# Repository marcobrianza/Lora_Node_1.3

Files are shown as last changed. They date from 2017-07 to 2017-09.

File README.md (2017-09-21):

# LoRa Node 1.3
PCB design by Mauro Alfieri and Marco Brianza

A LoRa shield for [WeMos](https://www.wemos.cc/) D1 mini boards  
Made to experiment a LoRaWan radio node and single channel gateway.
based on the projects:  

* WeMos-Lora [https://github.com/hallard/WeMos-Lora](https://github.com/hallard/WeMos-Lora)
* Wemos shield template [https://github.com/SuperHouse/D1MSHO](https://github.com/SuperHouse/D1MSHO)

PCB tested ready for manufactoring:  

* PCBWay [https://www.pcbway.com/project/shareproject/LoRa_Node_1_3.html](https://www.pcbway.com/project/shareproject/LoRa_Node_1_3.html)  
* PCBs.io [https://PCBs.io/share/4XRGg](https://PCBs.io/share/4XRGg) 

The reference BOM:  
[http://www.tme.eu/parking/d9c2f42be567335629e84ae2b3406e02d69110b7.html
](http://www.tme.eu/parking/d9c2f42be567335629e84ae2b3406e02d69110b7.html)

To use the board as node use this version of the lmic LoRa library:  
[https://github.com/marcobrianza/arduino-lmic](https://github.com/marcobrianza/arduino-lmic)  
It supports the LoraNode 1.3 pinout and fixes the radio power setting

Some practial examples with wrapping of the LMIC in more Arduinistic way are here:
[https://github.com/marcobrianza/LoraNode_Examples](https://github.com/marcobrianza/LoraNode_Examples)

To use it as gateway this repo:  
[https://github.com/marcobrianza/ESP-1ch-Gateway-v4.0/tree/LoraNode_1.3](https://github.com/marcobrianza/ESP-1ch-Gateway-v4.0/tree/LoraNode_1.3) 

## Usage Notes
The pinout is as the following table  
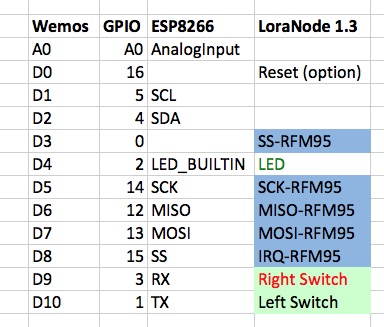
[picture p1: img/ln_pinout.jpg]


* I2C pins are free to be used for sensors or GPIO (pull up resistor are optional on the bottom) 
* D0 is free and can be connected to Reset with the "sleep" pad on the bottom of the board 
* The 2 switches (normally opened) are shared with the serial port pins
* The LED is connecred in parallel with the Built in LED of Wemos 

## Pictures

The board assembled top and bottom
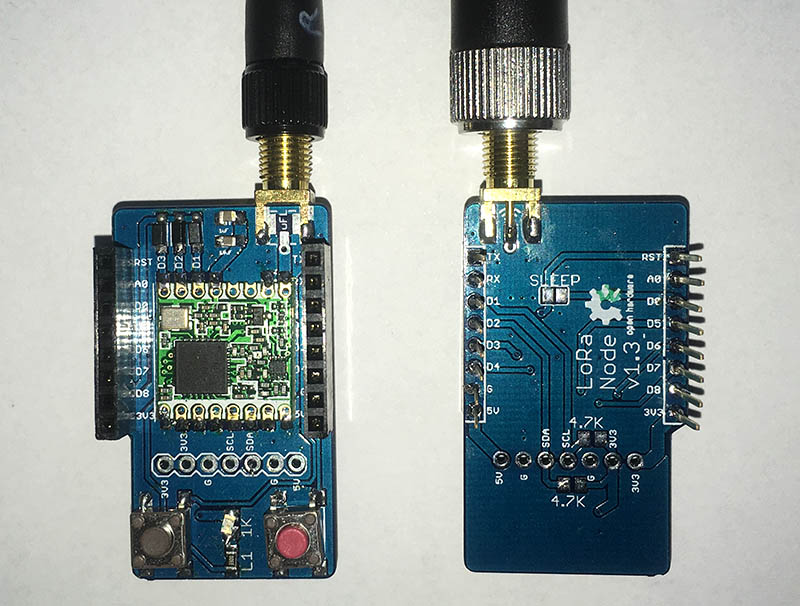
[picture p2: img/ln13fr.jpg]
LoraNode_1.3 top and bottom


The board in use as node and gateway with wemos oled display
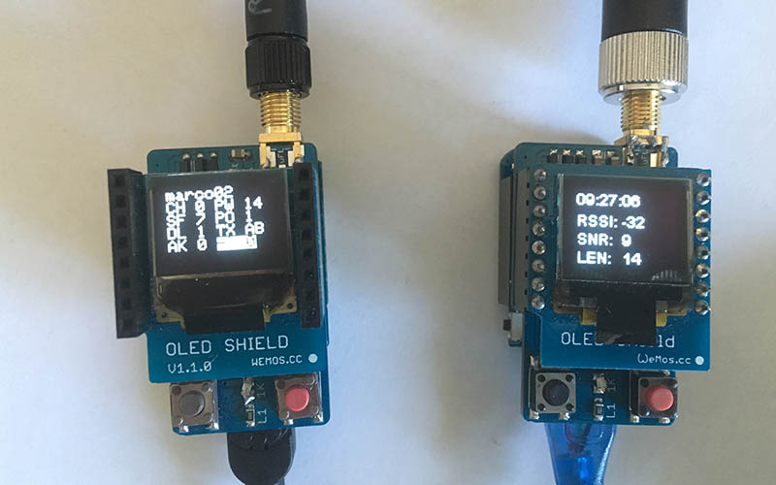
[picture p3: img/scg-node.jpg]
LoraNode_1.3 node and gateway


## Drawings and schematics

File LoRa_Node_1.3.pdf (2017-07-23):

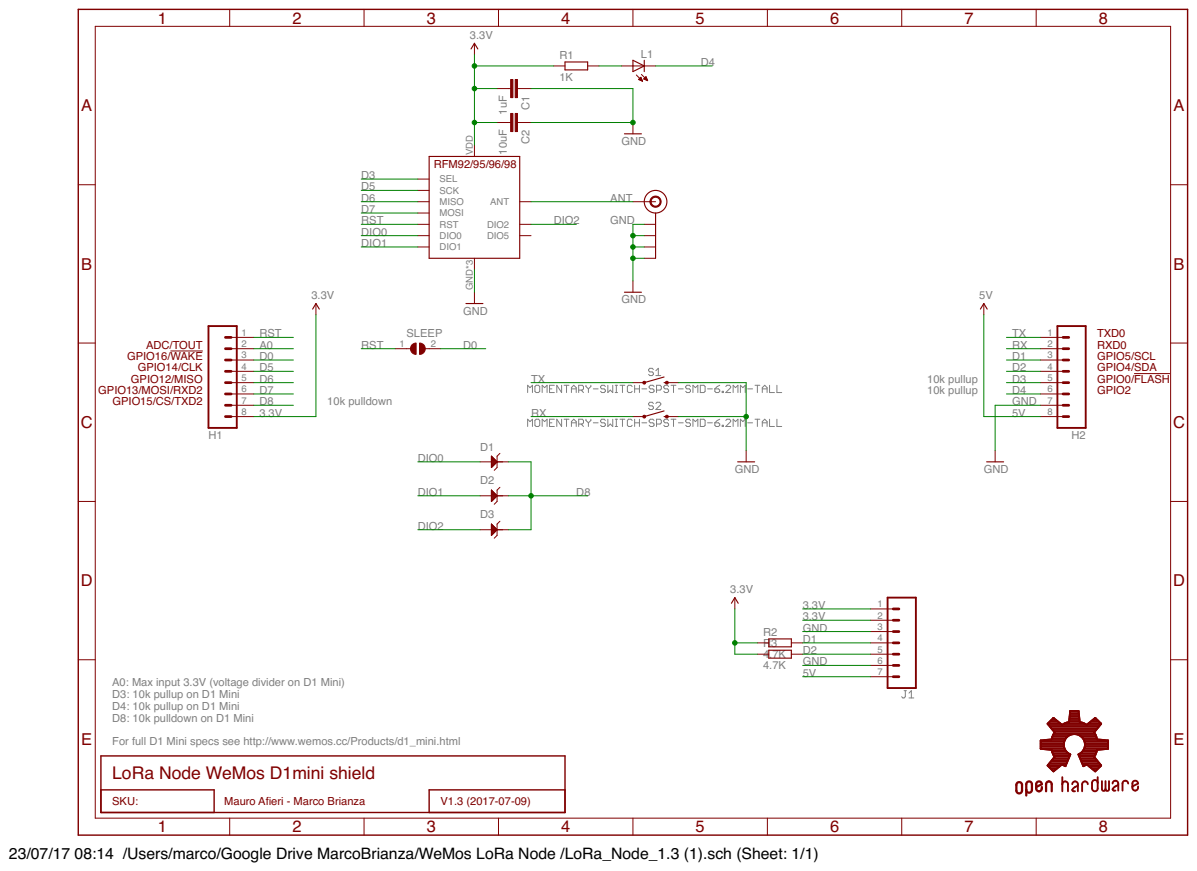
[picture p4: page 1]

A0: Max input 3.3V (voltage divider on D1 Mini)
D3: 10k pullup on D1 Mini
D4: 10k pullup on D1 Mini
D8: 10k pulldown on D1 Mini
For full D1 Mini specs see http://www.wemos.cc/Products/d1_mini.html
SKU: LoRa Node WeMos D1mini shield

23/07/17 08:14 /Users/marco/Google Drive MarcoBrianza/WeMos LoRa Node /LoRa_Node_1.3 (1).sch (Sheet: 1/1)

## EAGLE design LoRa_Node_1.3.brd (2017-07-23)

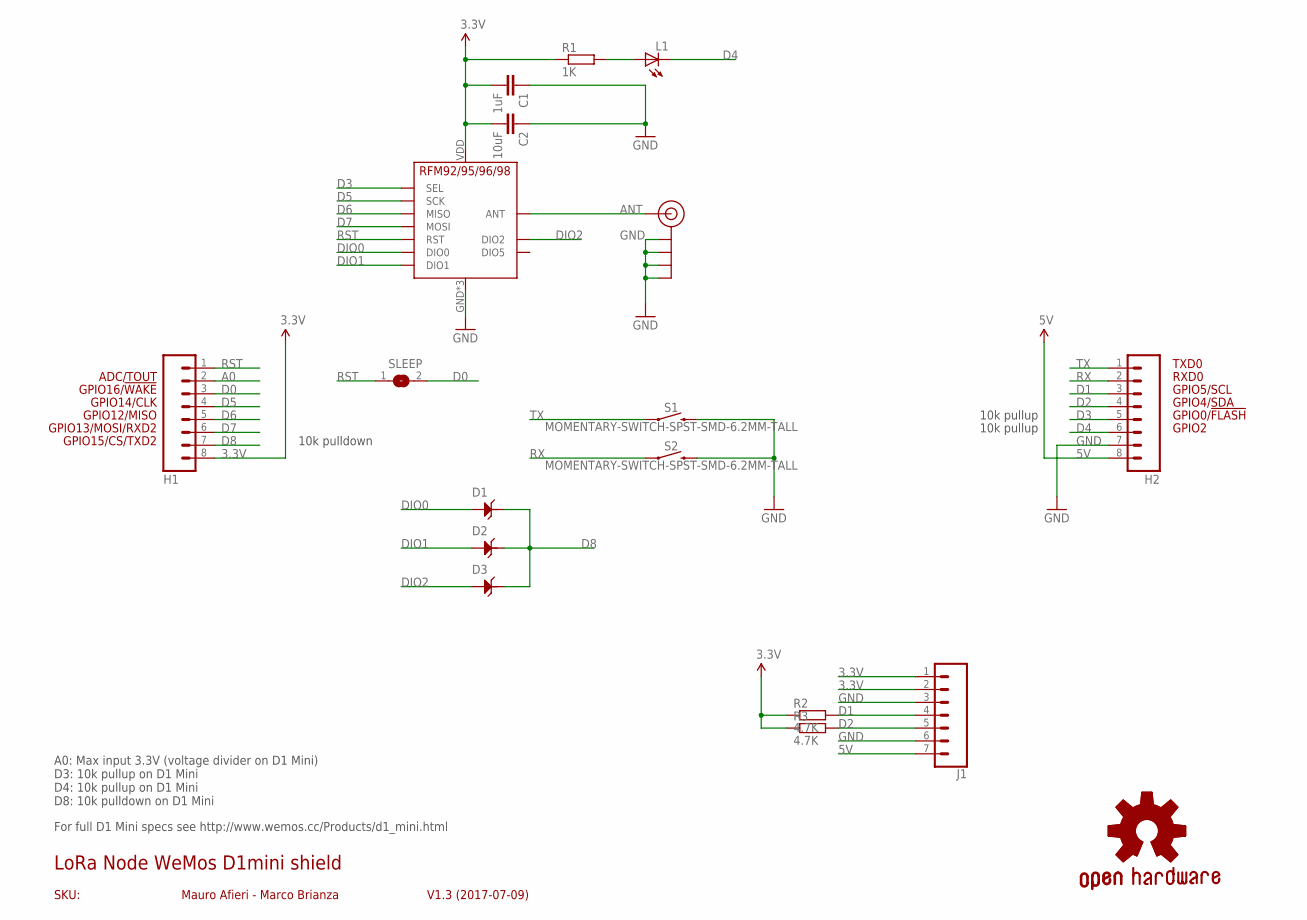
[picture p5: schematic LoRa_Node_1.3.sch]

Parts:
C1: 1uF; 0805-CAP-LARGEPADS
C2: 10uF; 0805-CAP-LARGEPADS
D1, D2, D3: D-ESD-2P-CESD5V0D1; SOD123-2.7X1.6
GOLD_ORB_SM1: OSHWLOGO_GOLD_ORB_SM; OSHW2
H1, H2: M08; 1X08
J1: CONN_07; 1X07
J$1: ANTENNATINY; SMA_UFL_PAD_TINY
L1: LEDCHIPLED_0805; CHIPLED_0805
R1: 1K; M0805
R2, R3: 4.7K; M0805
S1, S2: MOMENTARY-SWITCH-SPST-SMD-6.2MM-TALL; TACTILE_SWITCH_SMD_6.2MM_TALL
SLEEP: SJ
U$2: RFM95

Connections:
3.3V: C1.2, C2.2, H1.8, J1.1, J1.2, R1.1, R2.1, R3.1, U$2.VDD (VCC)
5V: H2.8, J1.7
A0: H1.2
ANT: J$1.ANT1 (SIGNAL), J$1.ANT2 (SIGNAL), J$1.ANT3 (SIGNAL), U$2.ANT
D0: H1.3, SLEEP.2
D1: H2.3, J1.4, R2.2
D2: H2.4, J1.5, R3.2
D3: H2.5, U$2.NSS (SEL)
D4: H2.6, L1.C
D5: H1.4, U$2.SCK
D6: H1.5, U$2.MISO
D7: H1.6, U$2.MOSI
D8: D1.2, D2.2, D3.2, H1.7
DIO0: D1.1, U$2.DIO0
DIO1: D2.1, U$2.DIO1
DIO2: D3.1, U$2.DIO2
GND: C1.1, C2.1, H2.7, J1.3, J1.6, J$1.GND1 (GND), J$1.GND2 (GND), J$1.GND3 (GND), J$1.GND4 (GND), S1.B2 (2), S2.B2 (2), U$2.GND, U$2.GND1 (GND), U$2.GND2 (GND)
unnamed: L1.A, R1.2
RST: H1.1, SLEEP.1, U$2.RST
RX: H2.2, S2.A2 (1)
TX: H2.1, S1.A2 (1)

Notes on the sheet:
GPIO2
GPIO0/!FLASH
GPIO12/MISO
GPIO4/SDA
GPIO5/SCL
RXD0
TXD0
GPIO13/MOSI/RXD2
GPIO14/CLK
GPIO15/CS/TXD2
GPIO16/!WAKE
SKU:
LoRa Node WeMos D1mini shield
V1.3 (2017-07-09)
Mauro Afieri - Marco Brianza
ADC/TOUT
A0: Max input 3.3V (voltage divider on D1 Mini) D3: 10k pullup on D1 Mini D4: 10k pullup on D1 Mini D8: 10k pulldown on D1 Mini
10k pulldown
10k pullup
For full D1 Mini specs see http://www.wemos.cc/Products/d1_mini.html

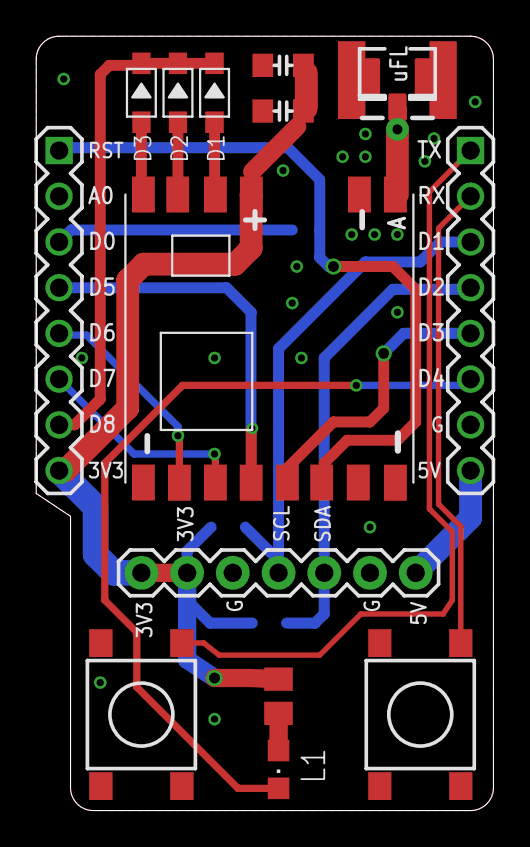
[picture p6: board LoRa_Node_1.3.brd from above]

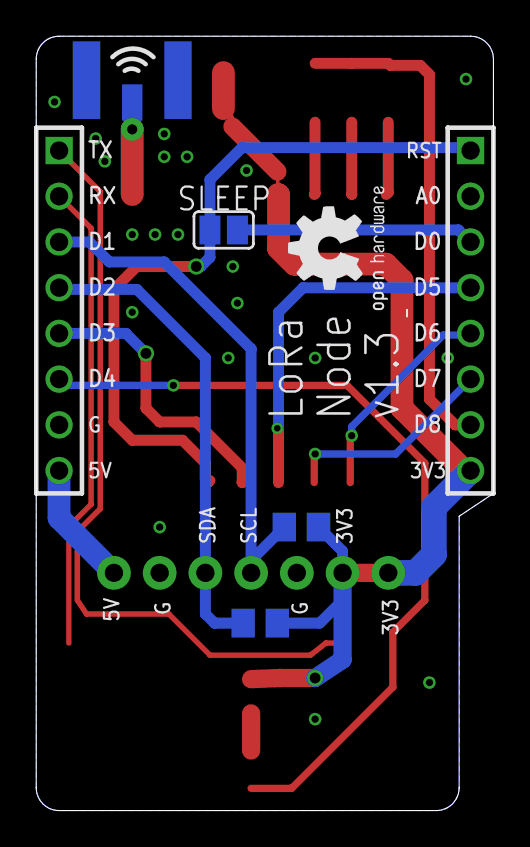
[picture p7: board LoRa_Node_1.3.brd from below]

Board: 2 copper layers, 25.4 x 43.0 mm, 18 parts (4 on the bottom side), 20 nets.

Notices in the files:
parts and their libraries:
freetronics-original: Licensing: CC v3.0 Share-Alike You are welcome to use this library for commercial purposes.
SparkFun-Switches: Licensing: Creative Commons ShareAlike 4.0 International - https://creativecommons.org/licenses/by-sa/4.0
